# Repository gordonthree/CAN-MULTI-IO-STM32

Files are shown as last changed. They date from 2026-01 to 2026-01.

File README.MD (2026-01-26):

# Analog / Digital Multi-IO Controller STM32
Compact module intended to interface with various analog and digital sensor modules, as well as provide generic digital outputs. An isolated CAN interface provides expansion capability with other modules, displays and sensors.

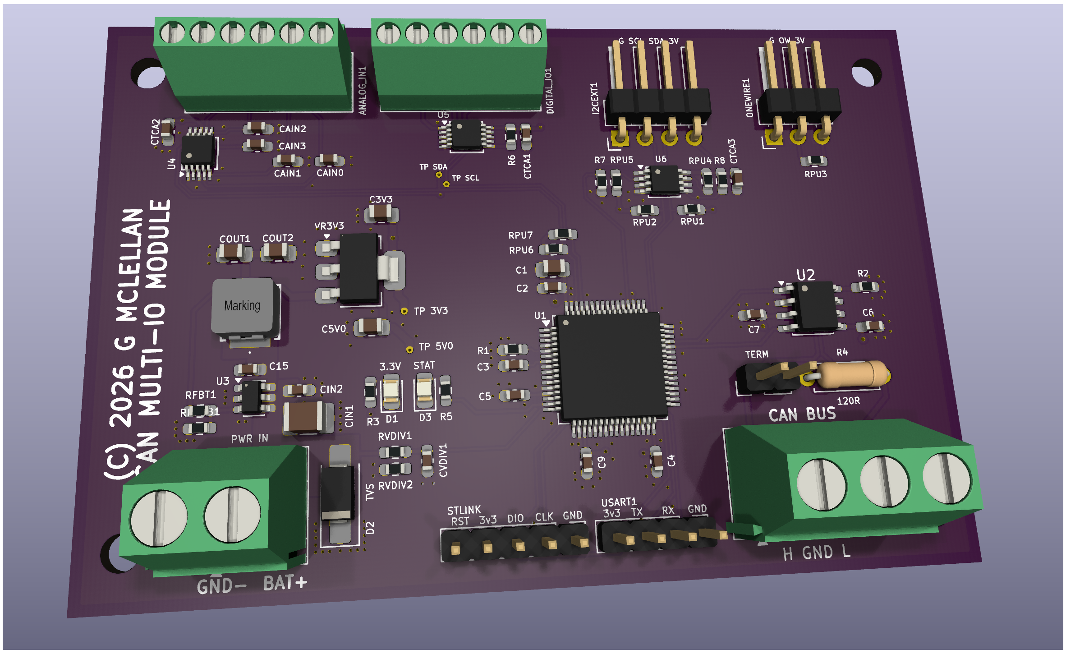
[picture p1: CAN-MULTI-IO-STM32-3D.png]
3d rendering of circuit board


# Multi-IO Node
* STM32G0B1RCT Microcontroller; 64mhz clock, 256k flash, 144k ram
* Automotive grade switch-mode power supply for 5v rail
* Automotive grade low-dropout linear supply for 3.3v rail
* 3-pin terminal block for CAN bus connection with drain
* Jumper selected CAN terminator resistor
* Analog header with four 16-bit ADC inputs
* GPIO header with four digital input/outputs
* Dedicated external I2C bus with interface buffer (hot swap capable)
* One-Wire bus header (USART1-TX)
* Two LED indicators for status, controlled by the micro
* Power input transient voltage protection diode for harsh environments
* Voltage divider to monitor input voltage
* Headers for USART3 serial port and the SWLINK programming connector

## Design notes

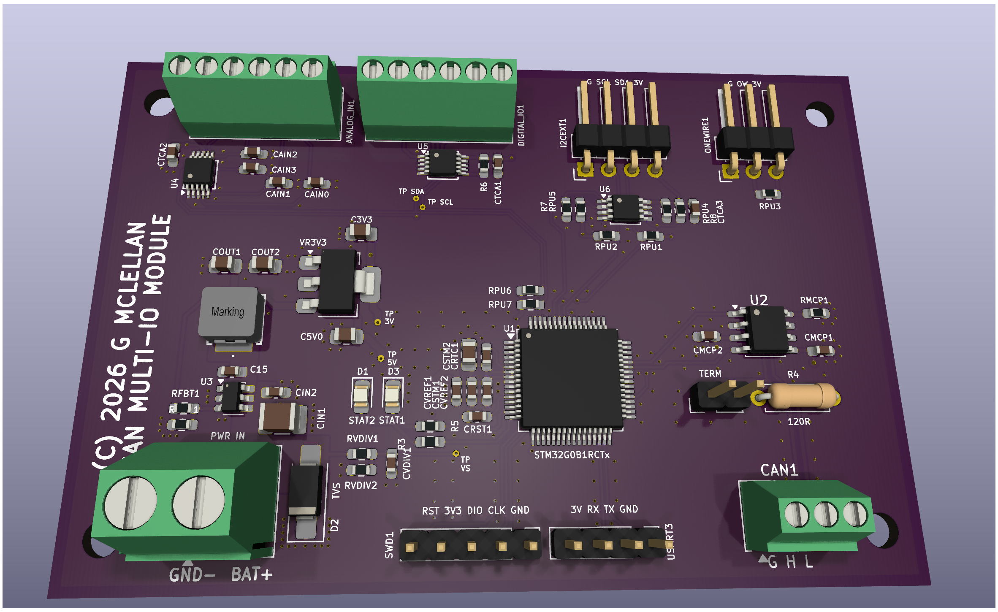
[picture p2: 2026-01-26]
CAN-MULTI-IO-STM32.png

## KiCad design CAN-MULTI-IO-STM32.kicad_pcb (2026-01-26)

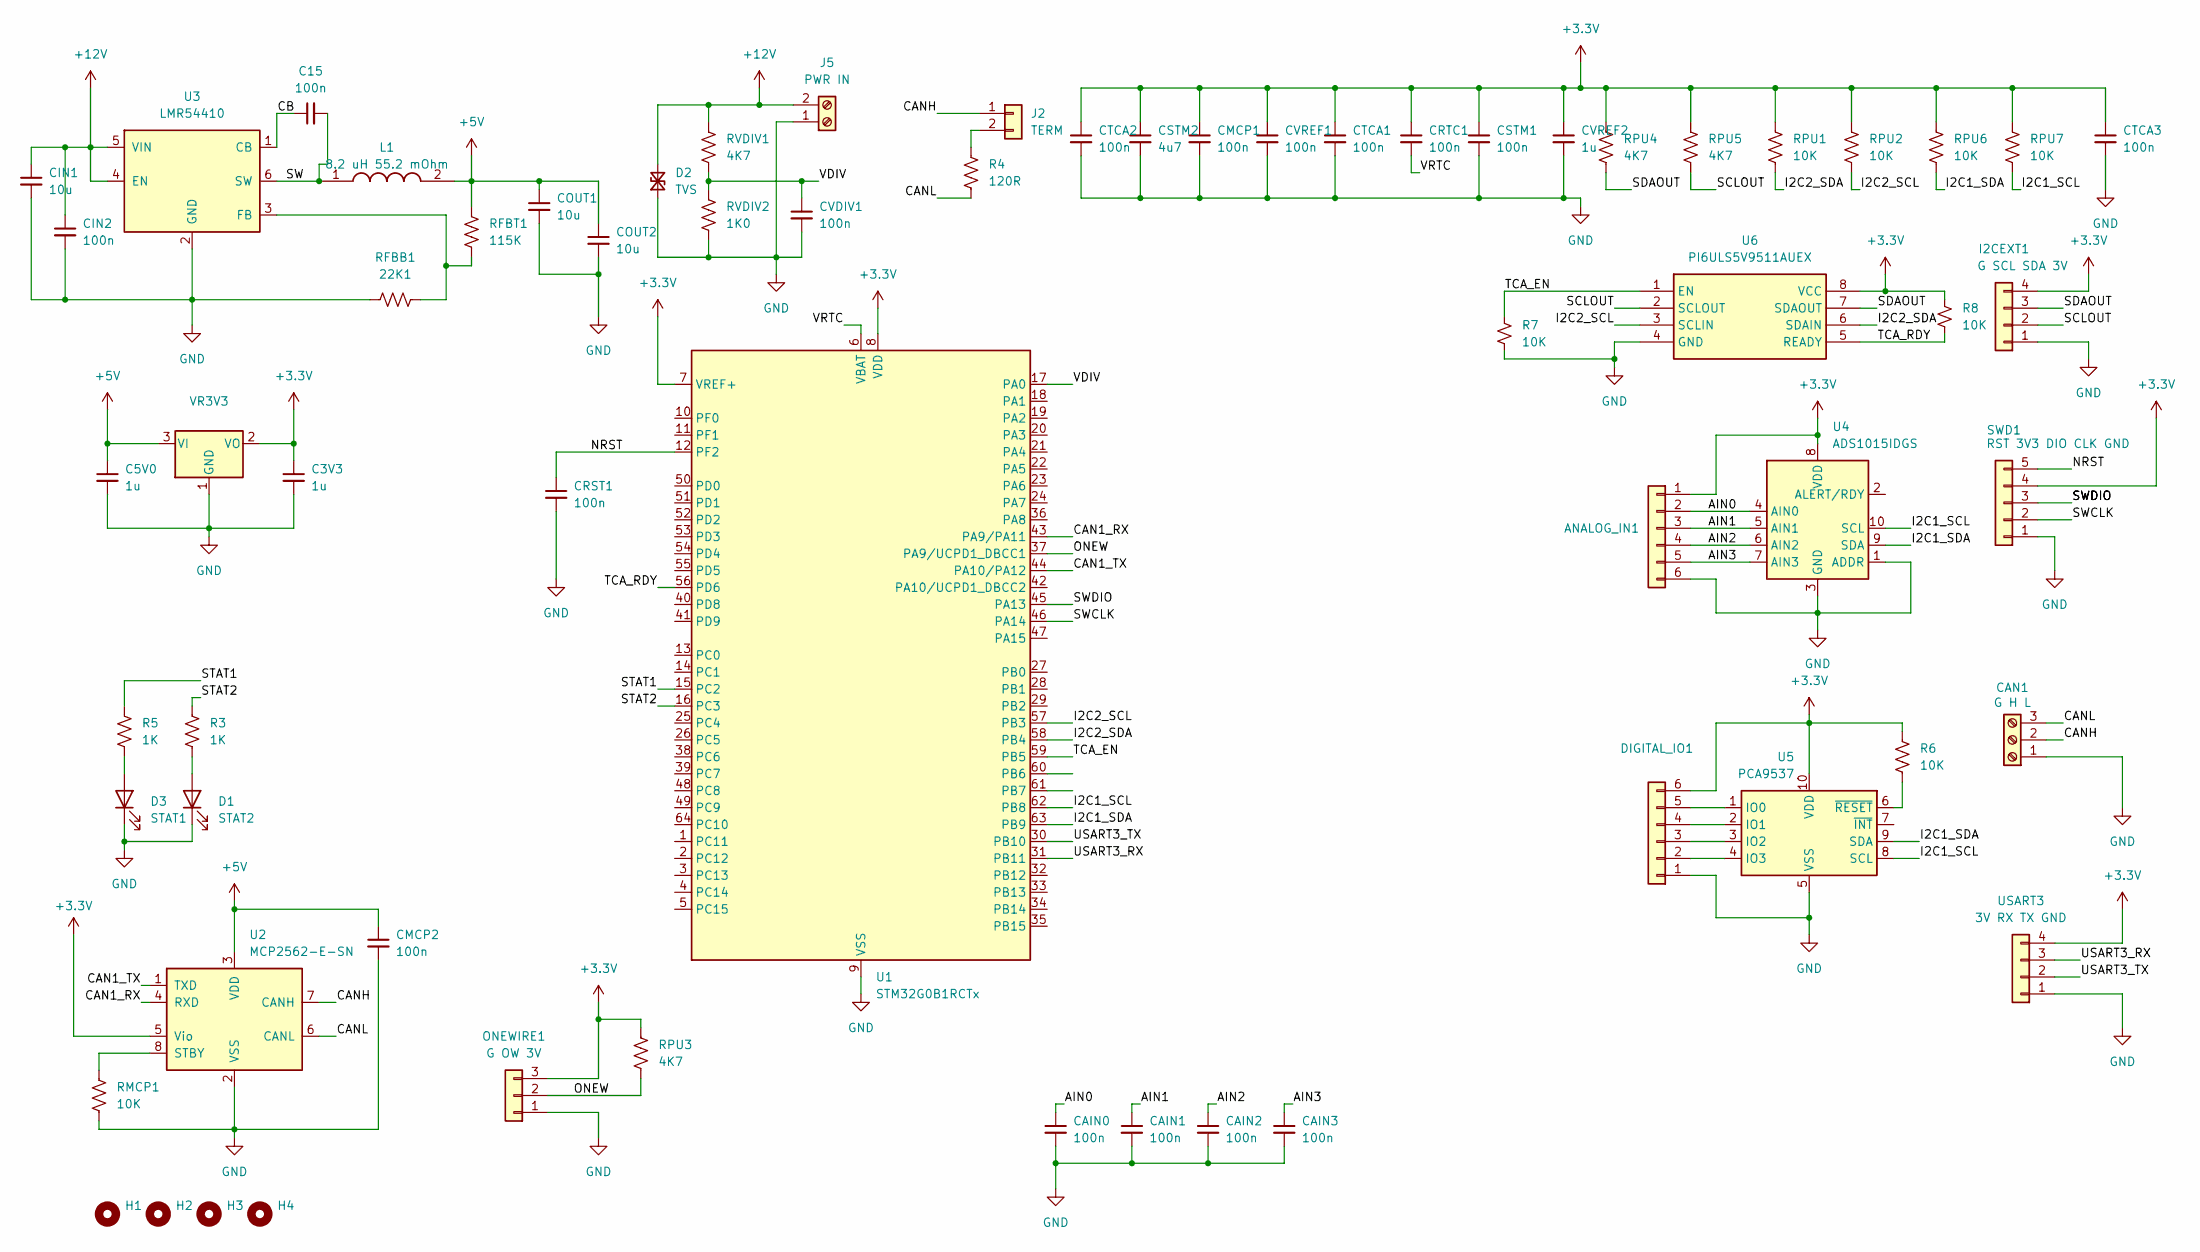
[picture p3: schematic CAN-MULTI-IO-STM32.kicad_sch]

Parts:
ANALOG_IN1: 1725698; TerminalBlock_Phoenix_MPT-0,5-6-2.54_1x06_P2.54mm_Horizontal
C3V3, C5V0: 1u; C_0805_2012Metric_Pad1.18x1.45mm_HandSolder
C15: 100n; C_0603_1608Metric_Pad1.08x0.95mm_HandSolder
CAIN0, CAIN1, CAIN2, CAIN3: 100n; C_0603_1608Metric_Pad1.08x0.95mm_HandSolder
CAN1: G H L; TerminalBlock_Phoenix_MPT-0,5-3-2.54_1x03_P2.54mm_Horizontal
CIN1: 10u; C_1210_3225Metric_Pad1.33x2.70mm_HandSolder
CIN2: 100n; C_0603_1608Metric_Pad1.08x0.95mm_HandSolder
CMCP1, CMCP2: 100n; C_0603_1608Metric_Pad1.08x0.95mm_HandSolder
COUT1, COUT2: 10u; C_0805_2012Metric_Pad1.18x1.45mm_HandSolder
CRST1: 100n; C_0603_1608Metric_Pad1.08x0.95mm_HandSolder
CRTC1: 100n; C_0603_1608Metric_Pad1.08x0.95mm_HandSolder
CSTM1: 100n; C_0603_1608Metric_Pad1.08x0.95mm_HandSolder
CSTM2: 4u7; C_0805_2012Metric_Pad1.18x1.45mm_HandSolder
CTCA1, CTCA2, CTCA3: 100n; C_0603_1608Metric_Pad1.08x0.95mm_HandSolder
CVDIV1: 100n; C_0603_1608Metric_Pad1.08x0.95mm_HandSolder
CVREF1: 100n; C_0603_1608Metric_Pad1.08x0.95mm_HandSolder
CVREF2: 1u; C_0603_1608Metric_Pad1.08x0.95mm_HandSolder
D1: STAT2; LED_0805_2012Metric_Pad1.15x1.40mm_HandSolder
D2: TVS; D_SMA_Handsoldering
D3: STAT1; LED_0805_2012Metric_Pad1.15x1.40mm_HandSolder
DIGITAL_IO1: 1725698; TerminalBlock_Phoenix_MPT-0,5-6-2.54_1x06_P2.54mm_Horizontal
H1, H2, H3, H4: MountingHole; MountingHole_3.2mm_M3_DIN965
I2CEXT1: G SCL SDA 3V; PinHeader_1x04_P2.54mm_Horizontal
J2: TERM; PinHeader_1x02_P2.54mm_Vertical
J5: PWR IN; TerminalBlock_Phoenix_MKDS-1,5-2_1x02_P5.00mm_Horizontal
L1: 8.2 uH 55.2 mOhm; SRP5030HMT2R2M; Mouser Part Number SRP5030HMT-8R2M
ONEWIRE1: G OW 3V; PinHeader_1x03_P2.54mm_Horizontal
R3, R5: 1K; R_0603_1608Metric_Pad0.98x0.95mm_HandSolder
R4: 120R; R_Axial_DIN0207_L6.3mm_D2.5mm_P7.62mm_Horizontal
R6, R7, R8: 10K; R_0603_1608Metric_Pad0.98x0.95mm_HandSolder
RFBB1: 22K1; R_0603_1608Metric_Pad0.98x0.95mm_HandSolder
RFBT1: 115K; R_0603_1608Metric_Pad0.98x0.95mm_HandSolder
RMCP1: 10K; R_0603_1608Metric_Pad0.98x0.95mm_HandSolder
RPU1, RPU2, RPU6, RPU7: 10K; R_0603_1608Metric_Pad0.98x0.95mm_HandSolder
RPU3, RPU4, RPU5: 4K7; R_0603_1608Metric_Pad0.98x0.95mm_HandSolder
RVDIV1: 4K7; R_0603_1608Metric_Pad0.98x0.95mm_HandSolder
RVDIV2: 1K0; R_0603_1608Metric_Pad0.98x0.95mm_HandSolder
SWD1: RST 3V3 DIO CLK GND; PinHeader_1x05_P2.54mm_Vertical
U1: STM32G0B1RCTx; LQFP-64_10x10mm_P0.5mm
U2: MCP2562-E-SN; SOIC-8_3.9x4.9mm_P1.27mm
U3: LMR54410; SOT-23-6
U4: ADS1015IDGS; TSSOP-10_3x3mm_P0.5mm
U5: PCA9537; TSSOP-10_3x3mm_P0.5mm
U6: PI6ULS5V9511AUEX; MSOP-8_3x3mm_P0.65mm
USART3: 3V RX TX GND; PinHeader_1x04_P2.54mm_Vertical
VR3V3: TLV1117-33; SOT-223-3_TabPin2

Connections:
+3.3V: ANALOG_IN1.1, C3V3.1, CMCP1.1, CRTC1.1, CSTM1.1, CSTM2.1, CTCA1.1, CTCA2.1, CTCA3.1, CVREF1.1, CVREF2.1, DIGITAL_IO1.6, I2CEXT1.4, ONEWIRE1.3, R6.1, R8.1, RPU1.2, RPU2.2, RPU3.2, RPU4.2, RPU5.2, RPU6.2, RPU7.2, SWD1.4, U1.7 (VREF+), U1.8 (VDD), U2.5 (Vio), U4.8 (VDD), U5.10 (VDD), U6.8 (VCC), USART3.4, VR3V3.2 (VO)
+5V: C5V0.1, CMCP2.1, COUT1.1, COUT2.1, L1.2, RFBT1.1, U2.3 (VDD), VR3V3.3 (VI)
+12V: CIN1.1, CIN2.1, D2.2 (A2), J5.2, RVDIV1.1, U3.4 (EN), U3.5 (VIN)
/AIN0: ANALOG_IN1.2, CAIN0.1, U4.4 (AIN0)
/AIN1: ANALOG_IN1.3, CAIN1.1, U4.5 (AIN1)
/AIN2: ANALOG_IN1.4, CAIN2.1, U4.6 (AIN2)
/AIN3: ANALOG_IN1.5, CAIN3.1, U4.7 (AIN3)
/CAN1_RX: U1.43 (PA9/PA11), U2.4 (RXD)
/CAN1_TX: U1.44 (PA10/PA12), U2.1 (TXD)
/CANH: CAN1.2, J2.1, U2.7 (CANH)
/CANL: CAN1.3, R4.2, U2.6 (CANL)
/CB: C15.1, U3.1 (CB)
/I2C1_SCL: RPU7.1, U1.62 (PB8), U4.10 (SCL), U5.8 (SCL)
/I2C1_SDA: RPU6.1, U1.63 (PB9), U4.9 (SDA), U5.9 (SDA)
/I2C2_SCL: RPU2.1, U1.57 (PB3), U6.3 (SCLIN)
/I2C2_SDA: RPU1.1, U1.58 (PB4), U6.6 (SDAIN)
/NRST: CRST1.1, SWD1.5, U1.12 (PF2)
/ONEW: ONEWIRE1.2, RPU3.1, U1.37 (PA9/UCPD1_DBCC1)
/SCLOUT: I2CEXT1.2, RPU5.1, U6.2 (SCLOUT)
/SDAOUT: I2CEXT1.3, RPU4.1, U6.7 (SDAOUT)
/STAT1: R5.2, U1.15 (PC2)
/STAT2: R3.2, U1.16 (PC3)
/SW: C15.2, L1.1, U3.6 (SW)
/SWCLK: SWD1.2, U1.46 (PA14)
/SWDIO: SWD1.3, U1.45 (PA13)
/TCA_EN: R7.1, U1.59 (PB5), U6.1 (EN)
/TCA_RDY: R8.2, U1.56 (PD6), U6.5 (READY)
/USART3_RX: U1.31 (PB11), USART3.3
/USART3_TX: U1.30 (PB10), USART3.2
/VDIV: CVDIV1.1, RVDIV1.2, RVDIV2.1, U1.17 (PA0)
/VRTC: CRTC1.2, U1.6 (VBAT)
GND: ANALOG_IN1.6, C3V3.2, C5V0.2, CAIN0.2, CAIN1.2, CAIN2.2, CAIN3.2, CAN1.1, CIN1.2, CIN2.2, CMCP1.2, CMCP2.2, COUT1.2, COUT2.2, CRST1.2, CSTM1.2, CSTM2.2, CTCA1.2, CTCA2.2, CTCA3.2, CVDIV1.2, CVREF1.2, CVREF2.2, D1.1 (K), D2.1 (A1), D3.1 (K), DIGITAL_IO1.1, I2CEXT1.1, J5.1, ONEWIRE1.1, R7.2, RFBB1.1, RMCP1.2, RVDIV2.2, SWD1.1, U1.9 (VSS), U2.2 (VSS), U3.2 (GND), U4.1 (ADDR), U4.3 (GND), U5.5 (VSS), U6.4 (GND), USART3.1, VR3V3.1 (GND)
unnamed: D1.2 (A), R3.1
unnamed: D3.2 (A), R5.1
unnamed: DIGITAL_IO1.2, U5.4 (IO3)
unnamed: DIGITAL_IO1.3, U5.3 (IO2)
unnamed: DIGITAL_IO1.4, U5.2 (IO1)
unnamed: DIGITAL_IO1.5, U5.1 (IO0)
unnamed: J2.2, R4.1
unnamed: RMCP1.1, U2.8 (STBY)
unnamed: RFBB1.2, RFBT1.2, U3.3 (FB)
unnamed: R6.2, U5.6 (~RESET)

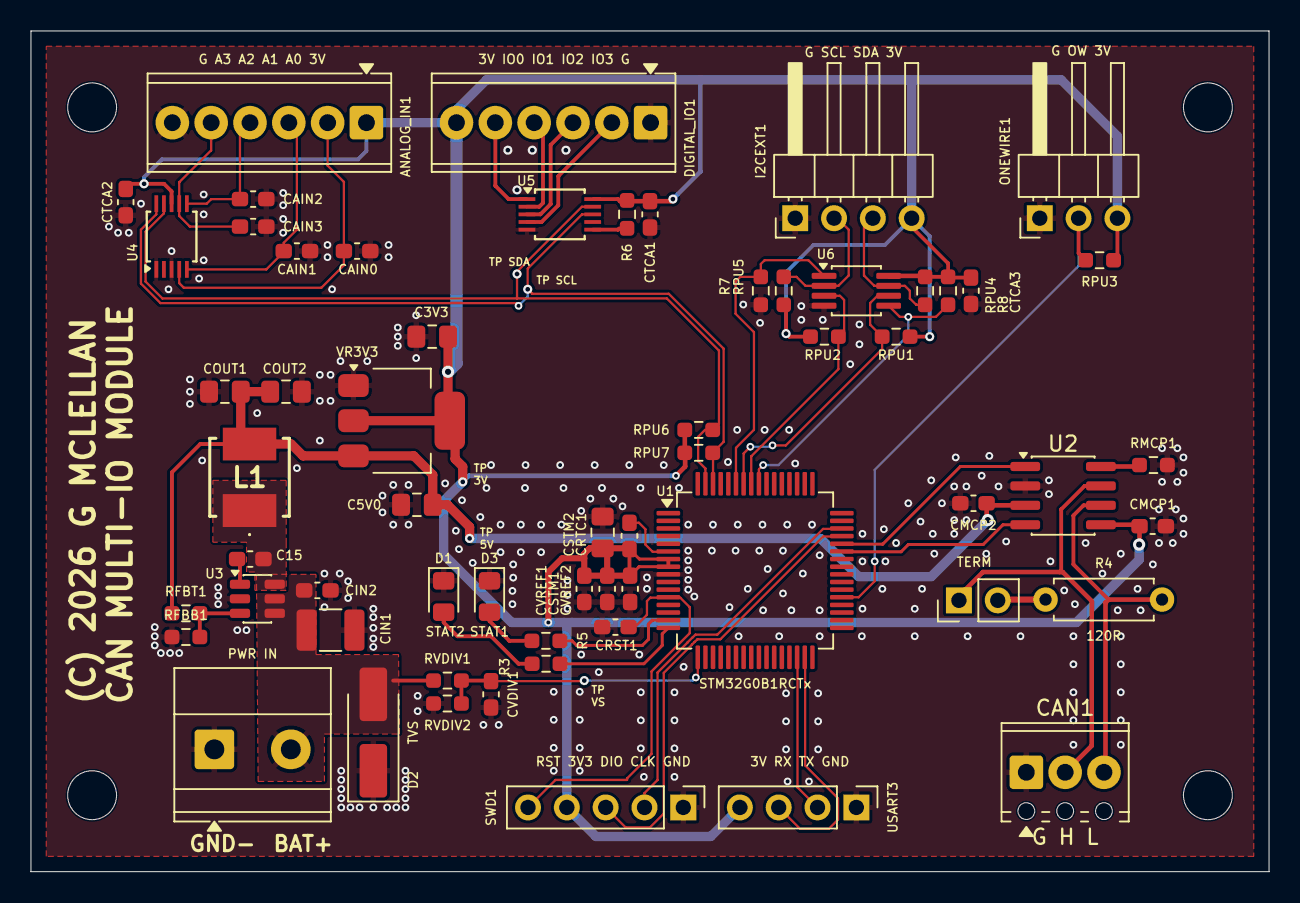
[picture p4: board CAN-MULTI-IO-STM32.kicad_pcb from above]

Board: 2 copper layers, 81.0 x 55.0 mm, 65 parts (0 on the bottom side), 42 nets.

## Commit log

2026-01-18 schematic and layout refinement
    [CAN-MULTI-IO-STM32.kicad_pcb, CAN-MULTI-IO-STM32.kicad_sch]
2026-01-18 final tweaks
    [CAN-MULTI-IO-STM32.kicad_pcb, CAN-MULTI-IO-STM32.kicad_sch]
2026-01-20 major rework to include SMPS and better analog input configuration
    [CAN-MULTI-IO-STM32.kicad_sch]
2026-01-20 optimized some connectors, switched to SMPS for 5v supply rail
    [CAN-MULTI-IO-STM32.kicad_pcb, CAN-MULTI-IO-STM32.kicad_sch]
2026-01-21 added i2c adc and gpio chips to isolate the mcu, lots of layout work
    [CAN-MULTI-IO-STM32.kicad_pcb, CAN-MULTI-IO-STM32.kicad_sch]
2026-01-21 lots of progress, lots to do
    [CAN-MULTI-IO-STM32.kicad_pcb, CAN-MULTI-IO-STM32.kicad_sch]
2026-01-21 first pass layout complete
    [CAN-MULTI-IO-STM32.kicad_pcb, CAN-MULTI-IO-STM32.kicad_sch]
2026-01-21 fixed issue with incorrect inductor
    [CAN-MULTI-IO-STM32.kicad_pcb, CAN-MULTI-IO-STM32.kicad_sch]
2026-01-21 silkscreen cleanup
    [CAN-MULTI-IO-STM32.kicad_pcb]
2026-01-21 fix 2.54mm terminal block issues
    [CAN-MULTI-IO-STM32.kicad_pcb, CAN-MULTI-IO-STM32.kicad_sch]
2026-01-21 fix a few footprint and drc issues
    [CAN-MULTI-IO-STM32.kicad_pcb, CAN-MULTI-IO-STM32.kicad_sch]
2026-01-21 rename gpio header
    [CAN-MULTI-IO-STM32.kicad_pcb, CAN-MULTI-IO-STM32.kicad_sch]
2026-01-21 DRC is clean no errors
    [CAN-MULTI-IO-STM32.kicad_pcb]
2026-01-26 switch to STM32G0B1 micro, refactor pcb layout
    [CAN-MULTI-IO-STM32.kicad_pcb, CAN-MULTI-IO-STM32.kicad_sch]
2026-01-26 final commit for tonight
    [CAN-MULTI-IO-STM32.kicad_sch]
2026-01-26 added ground stitching, silkscreen tweaks, refined 3v supply for STM
    [CAN-MULTI-IO-STM32.kicad_pcb]

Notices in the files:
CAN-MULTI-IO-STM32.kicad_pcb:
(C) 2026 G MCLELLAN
